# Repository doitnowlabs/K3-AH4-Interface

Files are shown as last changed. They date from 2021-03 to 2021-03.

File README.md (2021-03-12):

K3-AH4-Interface
================

A project that enables the use of the Icom AH4 autotuner with the Elecraft K3 and KX3 radios.

Edit -- March 2021: Greetings from the future! Many people have got in contact with me or my Dad asking for more information about this project over the ~7 years since it was created (if you contacted me and I didn't see the message/did not respond, I apologize!). Although it's a little late, I'm uploading all the files I have relating to the k3-ah4 interface so hopefully others can reproduce it without needing to rely on me checking my GitHub messages infrequently.

One note is that this project switches RS232 lines in and out of circuit with an analog switch, which definitely does not comply with the RS232 standard. The project worked great in the state I'm uploading it in, but it wouldn't pass a compliance test. As with all my work, use at your own risk, and have fun!

Schem. and board files are Eagle format. There's a free version of Eagle available to download if you don't own a copy already.

Ben

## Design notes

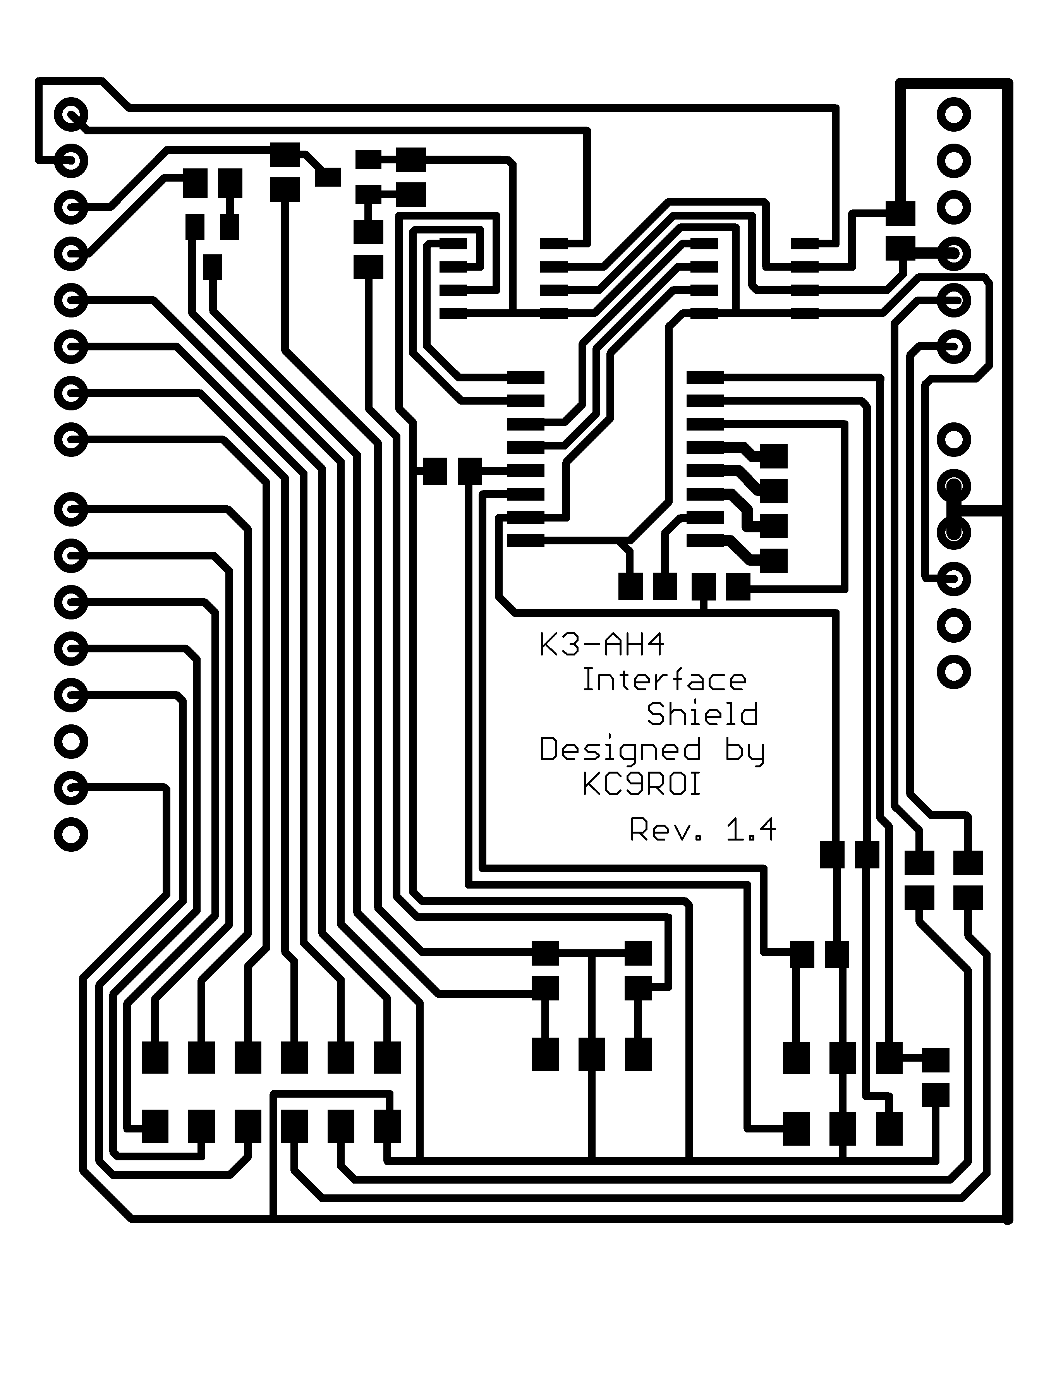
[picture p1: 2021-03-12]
K3_AH4 Files 31121/K3 Tuner smt/rev1.4.png

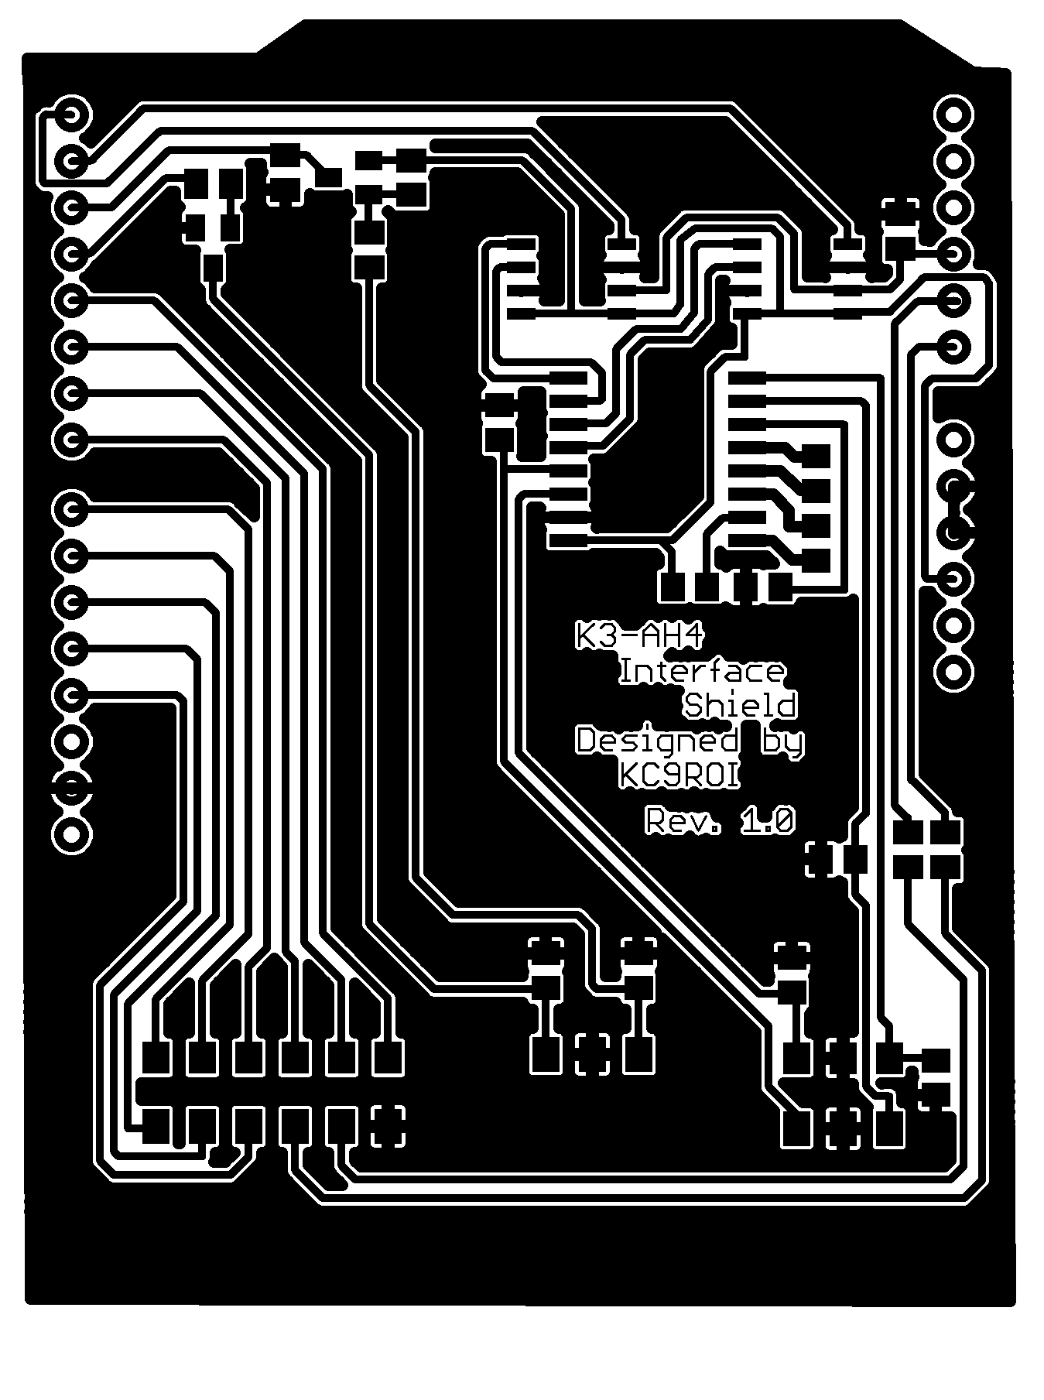
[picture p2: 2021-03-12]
K3_AH4 Files 31121/K3 Tuner smt/rev1.png

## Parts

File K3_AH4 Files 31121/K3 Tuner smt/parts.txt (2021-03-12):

Partlist

Exported from schematic_K3_Tuner.sch at 3/28/2014 2:09:03 AM

EAGLE Version 6.5.0 Copyright (c) 1988-2013 CadSoft

Assembly variant: 

Part     Value                 Device                    Package          Library          Sheet

C1       1uf                   C-USC0805                 C0805            rcl              1
C2       1uf                   C-USC0805                 C0805            rcl              1
C3       1uf                   C-USC0805                 C0805            rcl              1
C4       1uf                   C-USC0805                 C0805            rcl              1
C5       0.001uf               C-USC0805                 C0805            rcl              1
C6       0.001uf               C-USC0805                 C0805            rcl              1
C7       0.001uf               C-USC0805                 C0805            rcl              1
C8       0.001uf               C-USC0805                 C0805            rcl              1
C10      0.001uf               C-USC0805                 C0805            rcl              1
C11      0.001uf               C-USC0805                 C0805            rcl              1
IC1      MAX232ECWE            MAX232ECWE                SO16L            maxim            1
IC2      ADG419SOIC_N8         ADG419SOIC_N8             SOIC8            K3Library        1
IC3      ADG419SOIC_N8         ADG419SOIC_N8             SOIC8            K3Library        1
R2       10k                   R-US_M0805                M0805            resistor         1
R11      10k                   R-US_M0805                M0805            resistor         1
R12      10k                   R-US_M0805                M0805            resistor         1
R13      1k                    R-US_M0805                M0805            resistor         1
R14      100k                  R-US_M0805                M0805            resistor         1
R15      4.7k                  R-US_M0805                M0805            resistor         1
R16      4.7k                  R-US_M0805                M0805            resistor         1
T1                             MMBT3904LT1-NPN-SOT23-BEC SOT23-BEC        transistor       1
T2                             MMBT3906LT1-PNP-SOT23-BEC SOT23-BEC        transistor       1
U$1      ARDUINO_SHIELDNO_SILK ARDUINO_SHIELDNO_SILK     DUEMILANOVE_VIAS SparkFun-Boards  1
U$2      SMH-103-XX-X-S        SMH-103-XX-X-S            SMH-103-XX-X-S   SAMTEC_Headers   1
U$3      SMH-106-XX-X-D        SMH-106-XX-X-D            SMH-106-XX-X-D   SAMTEC_Headers   1
U$5      2X3.SMH.D             2X3.SMH.D                 SMH-103-XX-X-D   samtec_Headers_2 1

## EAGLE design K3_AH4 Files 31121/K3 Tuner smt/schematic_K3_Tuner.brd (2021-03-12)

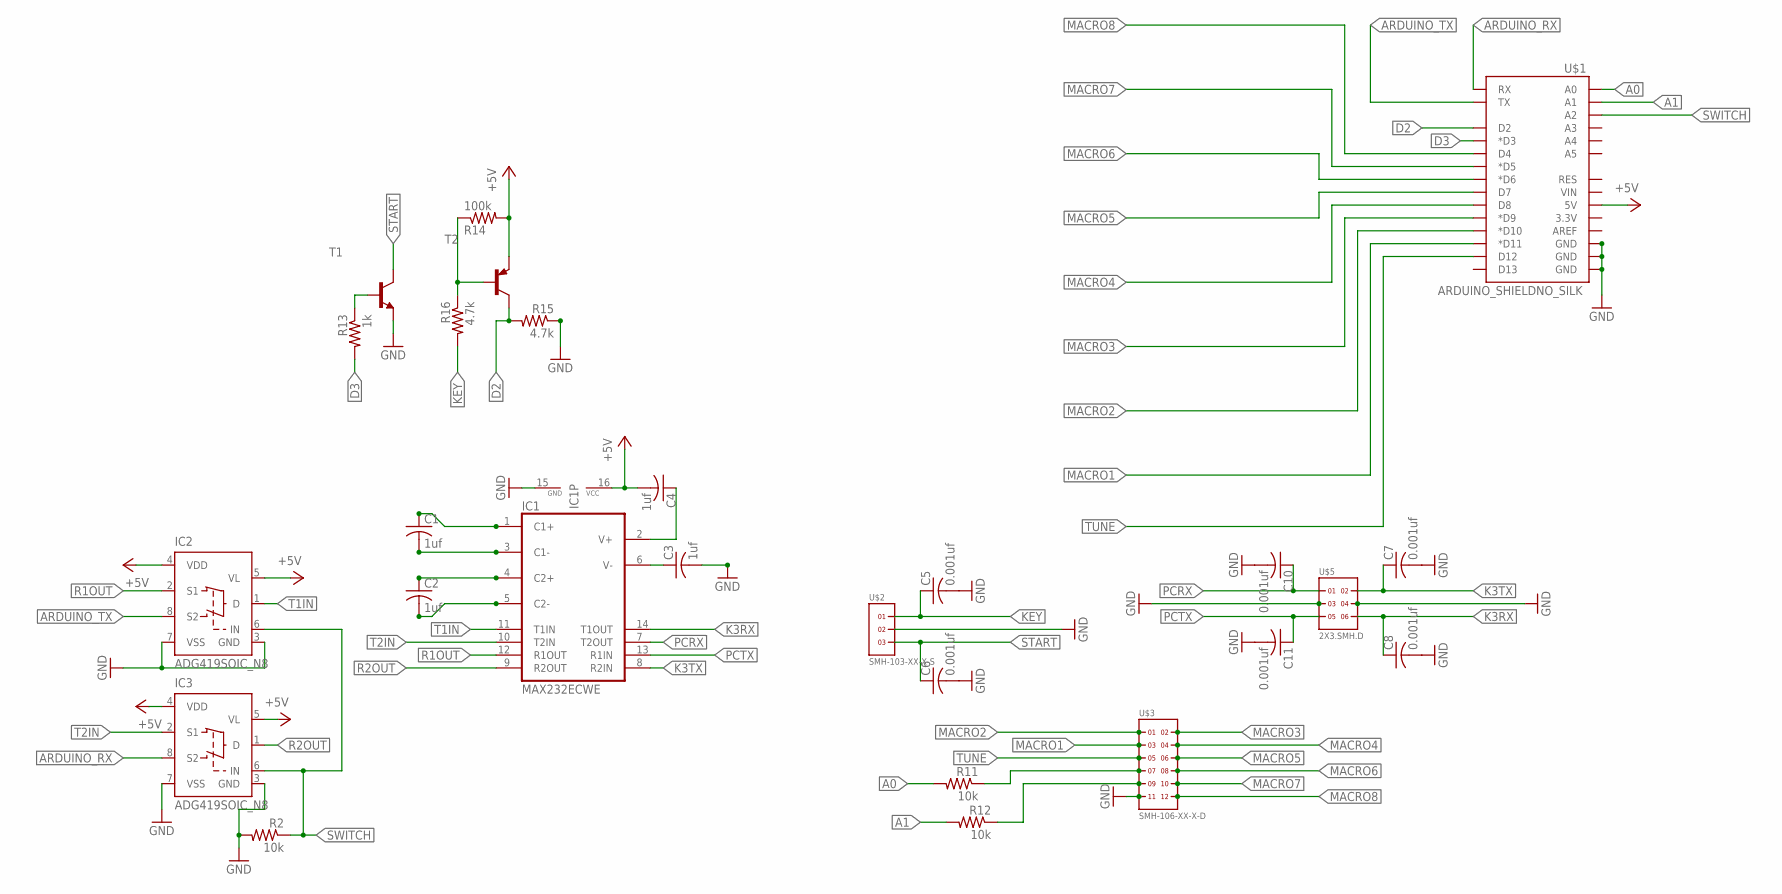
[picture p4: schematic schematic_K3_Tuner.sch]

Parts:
C1, C2, C3, C4: 1uf; C0805
C5, C6, C7, C8, C10, C11: 0.001uf; C0805
IC1: MAX232ECWE; SO16L
IC2, IC3: ADG419SOIC_N8; SOIC8
R2, R11, R12: 10k; M0805
R13: 1k; M0805
R14: 100k; M0805
R15, R16: 4.7k; M0805
T1: MMBT3904LT1-NPN-SOT23-BEC; SOT23-BEC
T2: MMBT3906LT1-PNP-SOT23-BEC; SOT23-BEC
U$1: ARDUINO_SHIELDNO_SILK; DUEMILANOVE_VIAS
U$2: SMH-103-XX-X-S
U$3: SMH-106-XX-X-D
U$5: 2X3.SMH.D; SMH-103-XX-X-D

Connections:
+5V: C4.2, IC1.16 (VCC), IC2.4 (VDD), IC2.5 (VL), IC3.4 (VDD), IC3.5 (VL), R14.2, T2.E, U$1.5V
A0: R11.2, U$1.A0
A1: R12.2, U$1.A1
ARDUINO_RX: IC3.8 (S2), U$1.RX
ARDUINO_TX: IC2.8 (S2), U$1.TX
D2: R15.2, T2.C, U$1.D2
D3: R13.2, U$1.D3 (*D3)
GND: C3.2, C5.2, C6.2, C7.2, C8.2, C10.2, C11.2, IC1.15 (GND), IC2.3 (GND), IC2.7 (VSS), IC3.3 (GND), IC3.7 (VSS), R2.2, R15.1, T1.E, U$1.GND@0 (GND), U$1.GND@1 (GND), U$1.GND@2 (GND), U$2.2, U$3.11, U$5.3, U$5.4
K3RX: C8.1, IC1.14 (T1OUT), U$5.6
K3TX: C7.1, IC1.8 (R2IN), U$5.2
KEY: C5.1, R16.2, U$2.1
MACRO1: U$1.D11 (*D11), U$3.3
MACRO2: U$1.D10 (*D10), U$3.1
MACRO3: U$1.D9 (*D9), U$3.2
MACRO4: U$1.D8, U$3.4
MACRO5: U$1.D7, U$3.6
MACRO6: U$1.D6 (*D6), U$3.8
MACRO7: U$1.D5 (*D5), U$3.10
MACRO8: U$1.D4, U$3.12
unnamed: R11.1, U$3.7
unnamed: R12.1, U$3.9
unnamed: C2.2, IC1.5 (C2-)
unnamed: C2.1, IC1.4 (C2+)
unnamed: C1.2, IC1.3 (C1-)
unnamed: C1.1, IC1.1 (C1+)
unnamed: C3.1, IC1.6 (V-)
unnamed: R13.1, T1.B
unnamed: R14.1, R16.1, T2.B
unnamed: C4.1, IC1.2 (V+)
PCRX: C10.1, IC1.7 (T2OUT), U$5.1
PCTX: C11.1, IC1.13 (R1IN), U$5.5
R1OUT: IC1.12 (R1OUT), IC2.2 (S1)
R2OUT: IC1.9 (R2OUT), IC3.1 (D)
START: C6.1, T1.C, U$2.3
SWITCH: IC2.6 (IN), IC3.6 (IN), R2.1, U$1.A2
T1IN: IC1.11 (T1IN), IC2.1 (D)
T2IN: IC1.10 (T2IN), IC3.2 (S1)
TUNE: U$1.D12, U$3.5

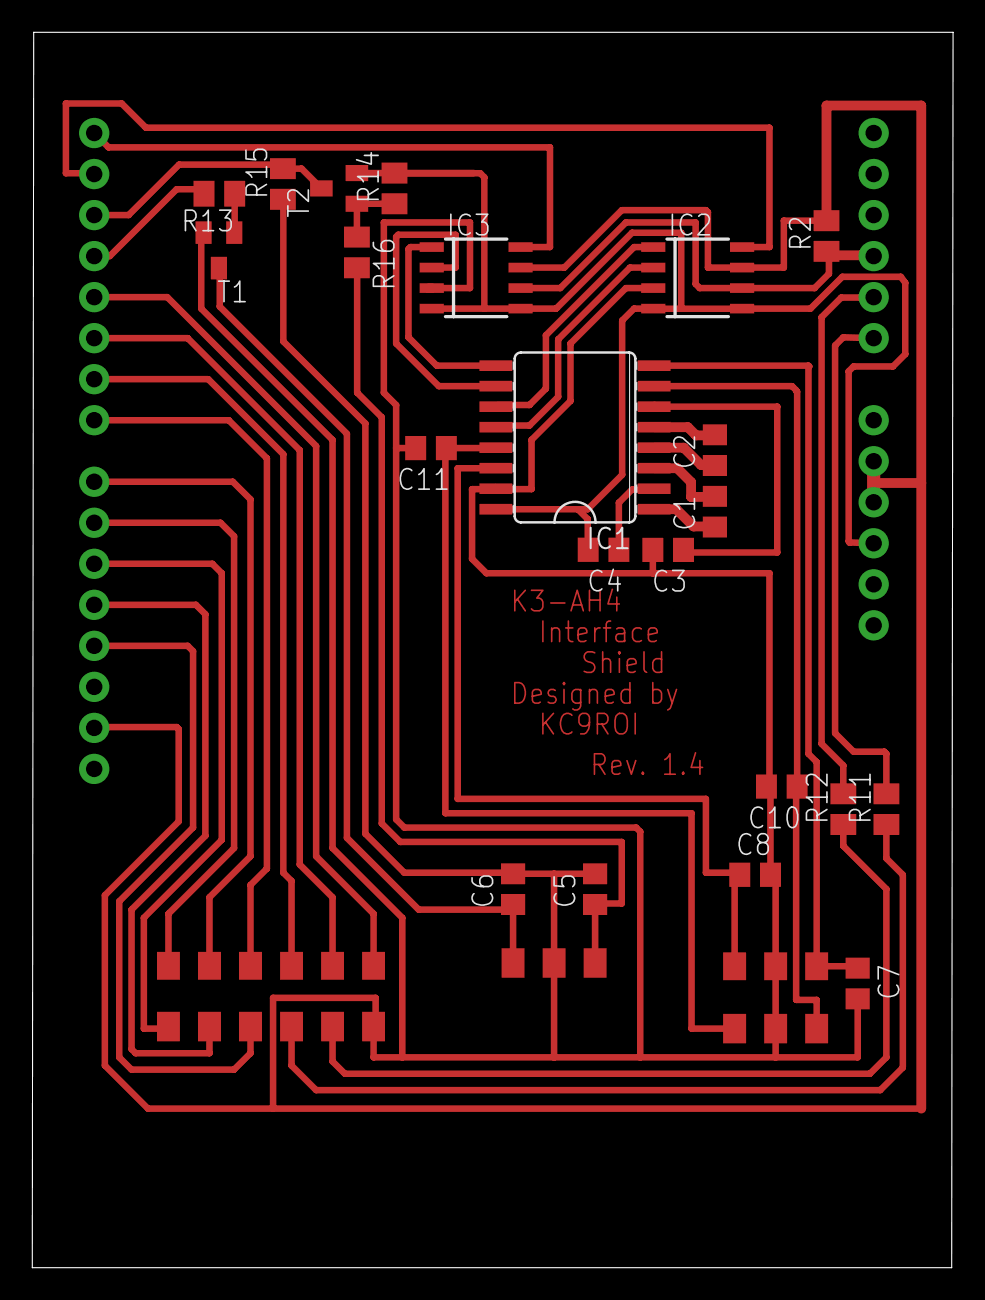
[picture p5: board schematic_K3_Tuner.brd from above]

Board: 2 copper layers, 57.0 x 76.5 mm, 26 parts (0 on the bottom side), 38 nets.

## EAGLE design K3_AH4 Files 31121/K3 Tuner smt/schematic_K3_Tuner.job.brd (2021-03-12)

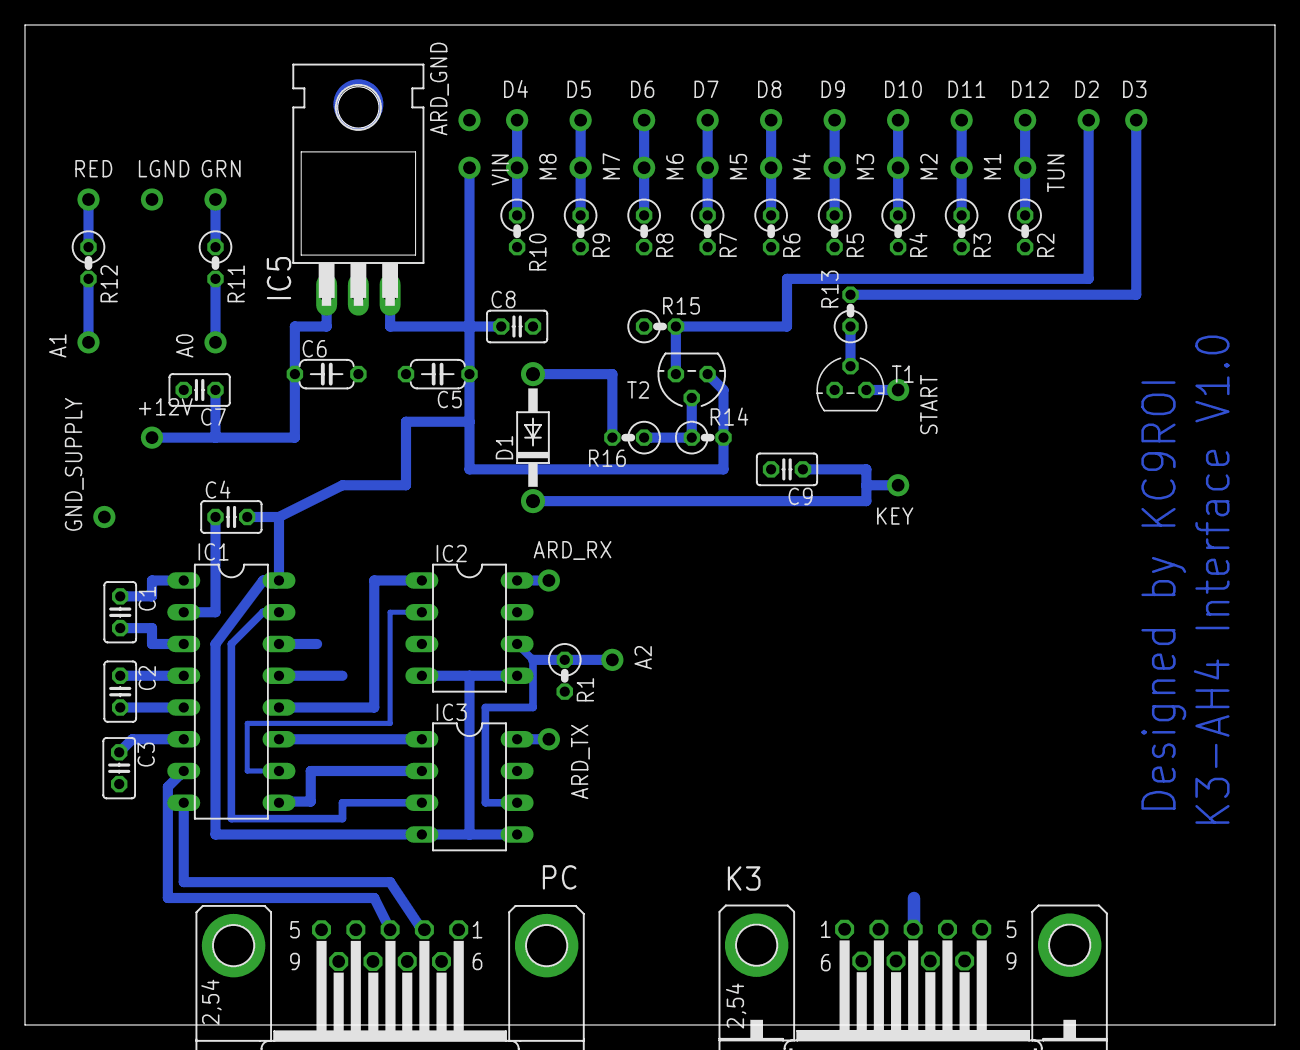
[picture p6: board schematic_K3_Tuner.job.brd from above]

Board: 2 copper layers, 100.0 x 80.0 mm, 68 parts (0 on the bottom side), 40 nets.

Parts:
+12V: 1X01-CLEANBIG
A0, A1, A2: 1X01-CLEANBIG
ARD_GND: 1X01-CLEANBIG
ARD_RX: 1X01-CLEANBIG
ARD_TX: 1X01-CLEANBIG
C1, C2, C3, C4: 1uf; C025-025X050
C5, C6: 10uf; C050-024X044
C7, C8, C9: 0.003uf; C025-025X050
D1: 1N4004; DO41-10
D2, D3, D4, D5, D6, D7, D8, D9, D10, D11, D12: 1X01-CLEANBIG
GND_SUPPLY: 1X01-CLEANBIG
GRN: 1X01-CLEANBIG
IC1: MAX232; DIL16
IC2, IC3: ADG419; DIL08
IC5: 7805T; TO220H
K3: M09HP
KEY: 1X01-CLEANBIG
LGND: 1X01-CLEANBIG
M1, M2, M3, M4, M5, M6, M7, M8: 1X01-CLEANBIG
PC: F09HP
R1, R2, R3, R4, R5, R6, R7, R8, R9, R10, R11, R12: 10k; 0207/2V
R13: 1k; 0207/2V
R14: 100k; 0207/2V
R15, R16: 4.7k; 0207/2V
RED: 1X01-CLEANBIG
START: 1X01-CLEANBIG
T1: 2N3904; TO92
T2: 2N3906; TO92
TUN: 1X01-CLEANBIG
VIN: 1X01-CLEANBIG

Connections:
+5V: C4.2, C5.1, C8.1, IC1.16, IC2.4, IC2.5, IC3.4, IC3.5, IC5.3, R14.2, T2.3, VIN.1
+12V: +12V.1, C6.1, C7.1, IC5.1
ARDUINO_RX: ARD_RX.1, IC2.8
ARDUINO_TX: ARD_TX.1, IC3.8
GND: ARD_GND.1, C3.2, C5.2, C6.2, C7.2, C8.2, C9.2, GND_SUPPLY.1, IC1.15, IC2.3, IC2.7, IC3.3, IC3.7, IC5.2, K3.5, K3.G1, K3.G2, LGND.1, PC.5, PC.G1, PC.G2, R1.2, R2.2, R3.2, R4.2, R5.2, R6.2, R7.2, R8.2, R9.2, R10.2, R15.1, T1.3
K3RX: IC1.14, K3.3
K3TX: IC1.13, K3.2
MACRO1: D11.1, M1.1, R3.1
MACRO2: D10.1, M2.1, R4.1
MACRO3: D9.1, M3.1, R5.1
MACRO4: D8.1, M4.1, R6.1
MACRO5: D7.1, M5.1, R7.1
MACRO6: D6.1, M6.1, R8.1
MACRO7: D5.1, M7.1, R9.1
MACRO8: D4.1, M8.1, R10.1
unnamed: R12.1, RED.1
unnamed: GRN.1, R11.1
unnamed: C2.2, IC1.5
unnamed: C2.1, IC1.4
unnamed: A1.1, R12.2
unnamed: C1.2, IC1.3
unnamed: C1.1, IC1.1
unnamed: A0.1, R11.2
unnamed: C3.1, IC1.6
unnamed: IC1.10, IC2.2
unnamed: R13.1, T1.2
unnamed: IC1.12, IC2.1
unnamed: IC1.11, IC3.1
unnamed: START.1, T1.1
unnamed: D3.1, R13.2
unnamed: R14.1, R16.1, T2.2
unnamed: C4.1, IC1.2
unnamed: D2.1, R15.2, T2.1
unnamed: D1.A, R16.2
unnamed: C9.1, D1.C, KEY.1
PCRX: IC1.7, PC.3
PCTX: IC1.8, PC.2
SWITCH: A2.1, IC2.6, IC3.6, R1.1
T2IN: IC1.9, IC3.2
TUNE: D12.1, R2.1, TUN.1

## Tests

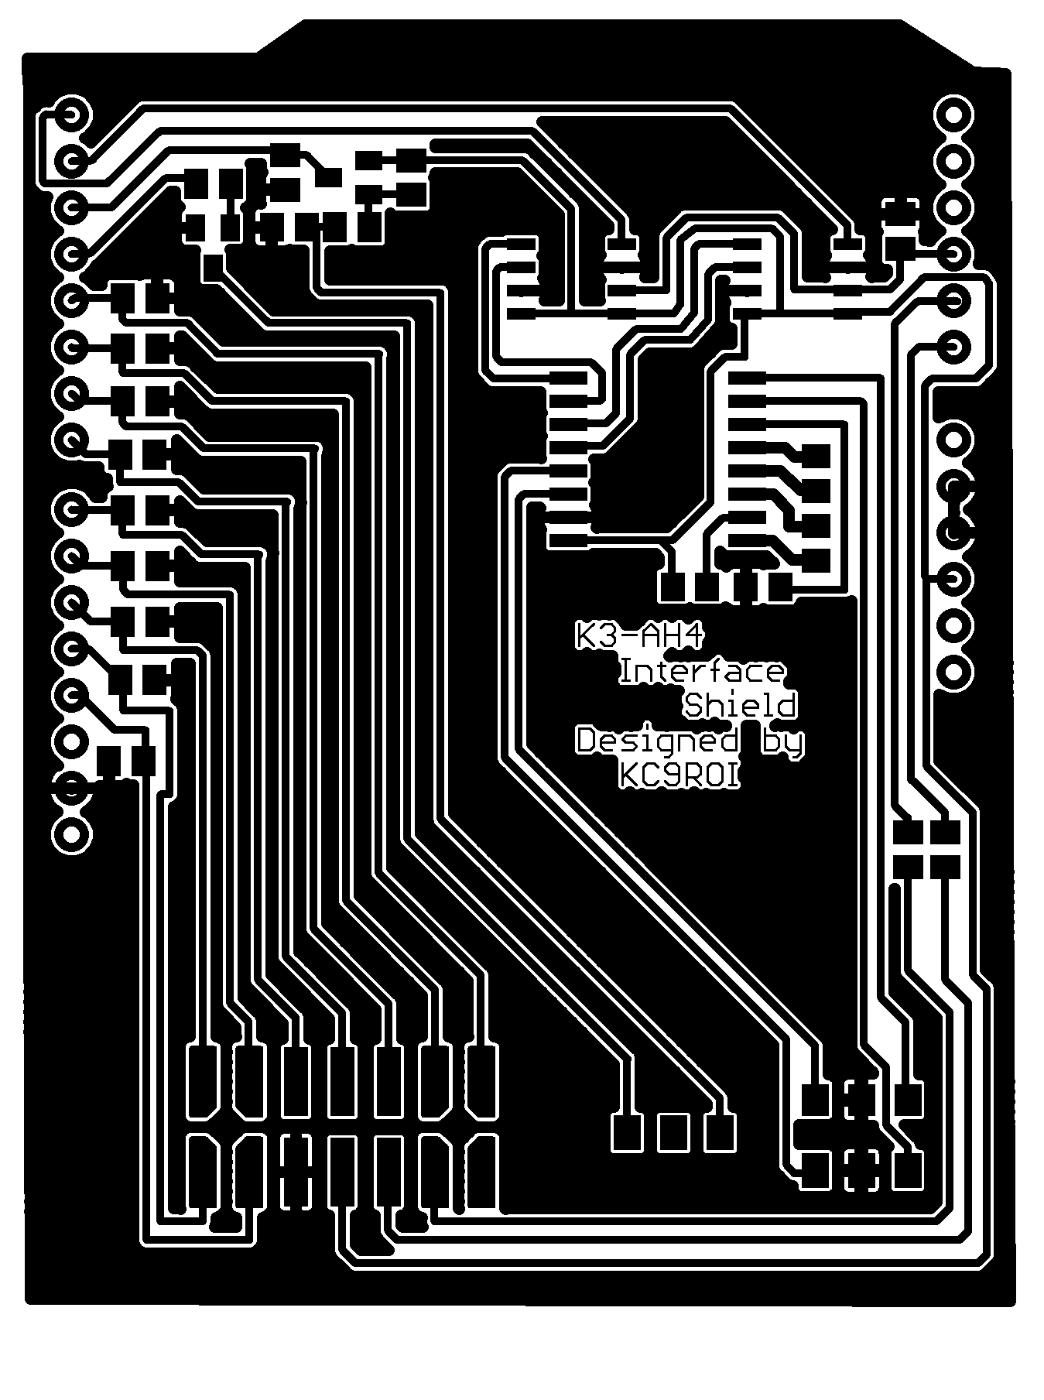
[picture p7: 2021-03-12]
K3_AH4 Files 31121/K3 Tuner smt/unfinished test.png

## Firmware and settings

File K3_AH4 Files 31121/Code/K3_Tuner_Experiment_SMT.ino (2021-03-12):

// This code is licenced by it's creator Ben Jacobs (KC9ROI) under the CC BY-NC-SA 3.0 licence:
// You are allowed to change, copy, reditribute, transmit, and adapt (remix) this code, as long as you licence your change, or adaptation under
// this or a similar licence, and you do not use this code, or any adaptations/changes of it for commercial purposes without the author's permission.
// Thanks!

int holdTime = 500;
String holdCommand1 = "FA00003560000;";
String holdCommand2 = "FA00007040000;";
String holdCommand3 = "FA00010106000;";
String holdCommand4 = "FA00014060000;";
String holdCommand5 = "FA00018096000;";
String holdCommand6 = "FA00021060000;";
String holdCommand7 = "FA00001810000;";
String holdCommand8 = "FA00028060000;";
String message;
char inByte = ' ';

int tuneBtn = 12;
int macroBtn = 0;
int start = 3;
int key = 2;
int grnLED = A0;
int redLED = A1;
int serialSwitch = A2;

int tuneStatus; 
int lightStatus;

int tuneBtnState = 0;
int macroBtnState = 0;
int i;

unsigned long timestamp = 0;

void setup() 
{
  Serial.begin(19200);
  pinMode(tuneBtn, INPUT_PULLUP); // Button that activates the tune code
  pinMode(11, INPUT_PULLUP); // macro 1 ...
  pinMode(10, INPUT_PULLUP);
  pinMode(9, INPUT_PULLUP);
  pinMode(8, INPUT_PULLUP);
  pinMode(7, INPUT_PULLUP);
  pinMode(6, INPUT_PULLUP);
  pinMode(5, INPUT_PULLUP);
  pinMode(4, INPUT_PULLUP); // ... through macro 8
  pinMode(start, OUTPUT); //Start line (white wire from tuner)
  pinMode(grnLED, OUTPUT); //Green half of bi color LED
  pinMode(redLED, OUTPUT); //Red half of bi color LED
  pinMode(key, INPUT); //Key line (Green from tuner)
  digitalWrite(serialSwitch, LOW);
  digitalWrite(redLED, LOW);
  digitalWrite(grnLED, HIGH);
}

void loop() // Main loop 
{
  tuneBtnState = digitalRead(tuneBtn); // Read tune button
  if (tuneBtnState == LOW) //With internal pullups, LOW means the button has been pressed
  {
   delay(holdTime);
   tuneBtnState = digitalRead(tuneBtn);
   if (tuneBtnState == LOW)
   {
    digitalWrite(start, HIGH);
    delay(70);
    digitalWrite(start, LOW);
    lightStatus = 2;
   }
   else
   {
    delay(100);
    digitalWrite(serialSwitch, HIGH); //Set the serial line to arduino via the ADG419 analog switches
    delay(100);
    digitalWrite(start, HIGH);
    timestamp = millis();
    while (1 > 0)
    {
     if (millis() - timestamp >= 500)
     {
      digitalWrite(start, LOW); 
      lightStatus = 0;
      goto tuneEnd;  // Key line timed out. Check that the tuner is plugged in and try again.
     } 
     if (digitalRead(key) == HIGH) // Wait for key line to go high, indicating that the Rig should start Txing
     {
      digitalWrite(start, LOW); //KEY is high, turn off START
      break;
     }
    }
    
    // No errors so far, KEY was detected, start tuning operation 
    
    Serial.print("SWH16;"); //Enter tune mode, start TXing
    while(1 > 0)
    {
      if (digitalRead(key) == LOW) // Wait for KEY to go LOW
      {
        delay(120); // Wait 120ms
        if (digitalRead(key) == HIGH) // If after 120ms the KEY line is back HIGH again, a pulse has occoured (Bad tune status)
        {
        lightStatus = 0;

         break;
        }
        else
        {
         lightStatus = 1;

         break;
        }
      }
    }

    tuneEnd: // Tuning has finished, or an error has occoured causing a jump to this line. Clear serial buffer and query the K3 as to if it is TXing still or not. 
 
    while (Serial.available() > 0) // The folowing code clears the Arduino's serial buffer so that, in the event a user calls an unprogrammed (empty) macro, the ";" character(s)
    {                             // returned by the empty macro call are erased, as to ensure that the next command sent to the K3 returns a valid response.
     inByte = Serial.read();    
    }
  
    Serial.print("TQ;"); // Transmit query command
    message = "";
    timestamp = millis(); // Store the current time in a variable called timestamp
    while (1 > 0)
    {
     if (Serial.available() > 0) // If serial is available
     {
      inByte = Serial.read(); // Read one byte of it into inByte
      message += inByte; // Add inByte to message
     }
      if (message == "TQ1;") // If the K3 is still TXing (As it should be), tell it to stop and leave the loop.
      {
       Serial.print("SWT16;"); // Press the TX button (toggle on/off)
       lightStatus = 1;
       break;
      }
      if (message == "TQ0;") // If the K3 is not TXing, since I have not told it to stop yet, there must be an error. Turn on the RED (Error) led. (See next comment)
      {
       //lightStatus = 0; // Add in these two lines if you want the RED led come on. 
       //light();
       break;
      }
      if (millis() - timestamp >= 200) // If timestamp - the current time >= 200ms
      {          
       lightStatus = 0; // There was no response from the  k3, so turn on the error LED
       break;
      }
    
    }

   }
    light();
    delay(100);
    digitalWrite(serialSwitch, LOW); // switch off switch
    while (tuneBtnState == LOW)
    {
     tuneBtnState = digitalRead(tuneBtn);
     delay(5); 
    }
   }
   
   
   // Read macro buttons one after another in this FOR loop. Call macroFunction() if one is high to handle it.
   for (macroBtn = 4; macroBtn < 12; macroBtn += 1)
   {   
    macroBtnState = digitalRead(macroBtn);
    if (macroBtnState == LOW)
    {
      macroFunction();
    }
   }
}

void macroFunction()
{
  delay(holdTime);
  macroBtnState = digitalRead(macroBtn);
  digitalWrite(serialSwitch, HIGH); 

  if (macroBtnState == HIGH)
  {   
   switch (macroBtn)
   {
     case 4:
      Serial.print(holdCommand8);
      break;
     case 5:
      Serial.print(holdCommand7);
      break;
     case 6:
      Serial.print(holdCommand6);
      break;
     case 7:
      Serial.print(holdCommand5);
      break;
     case 8:
      Serial.print(holdCommand4);
      break;
     case 9:
      Serial.print(holdCommand3);
      break;
     case 10:
      Serial.print(holdCommand2);
      break;
     case 11:
      Serial.print(holdCommand1);
      break;
   } 
  }
  else
  {
   switch (macroBtn)
   {
     case 4:
      Serial.print("SWH39;");
      break;
     case 5:
      Serial.print("SWH35;");
      break;
     case 6:
      Serial.print("SWH31;");
      break;
     case 7:
      Serial.print("SWH21;");
      break;
     case 8:
      Serial.print("SWT39;");
      break;
     case 9:
      Serial.print("SWT35;");
      break;
     case 10:
      Serial.print("SWT31;");
      break;
     case 11:
      Serial.print("SWT21;");
      break;
   }
  }
  delay(100);
  digitalWrite(serialSwitch, LOW); // switch off switch
  while (macroBtnState == LOW)
  {
   macroBtnState = digitalRead(macroBtn);
   delay(5); 
  }
}

void light() // Function that changes the LED's color according to the contents of the "lightStatus" variable
{
 switch(lightStatus)
 {
   case 0: // 0 = red (Error/bad tune)
    digitalWrite(grnLED, LOW);
    digitalWrite(redLED, HIGH);
    i = 0;
    while (i < 4)
    {
    digitalWrite(redLED, LOW); 
    delay(200); 
    digitalWrite(redLED, HIGH);
    delay(200);
    i+=1;
    }
    break;
   case 1: // 1 = green (No errors/good tune)
    digitalWrite(redLED, LOW);
    digitalWrite(grnLED, HIGH);
    break;
   case 2: // 2 = orange (tuner out of circuit; "Un-tune")
    digitalWrite(redLED, HIGH);
    digitalWrite(grnLED, HIGH);
    break;
 }
}

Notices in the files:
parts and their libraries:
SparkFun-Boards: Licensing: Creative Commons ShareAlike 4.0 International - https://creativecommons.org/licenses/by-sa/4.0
